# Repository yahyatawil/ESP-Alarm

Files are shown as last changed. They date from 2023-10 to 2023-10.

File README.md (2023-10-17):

# ESP-Alarm
This project was built for [Allaboutcircuit](https://www.allaboutcircuits.com/projects/esp-alarm-set-alarms-from-your-mobile-phone-esp8266-arduino-uno-wifi-iot/) published in 2017. 



## Hardware 
* Arduino UNO or any compatible board (optional).
* ATmega328P (optional).
* ESP8266 Wi-Fi module, ESP-01 model.
* 1.44-inch TFT display module.
* TP4056 breakout board (Li-ion battery charger).
* DS1307 (RTC chip)
* 74LVX4245 (5V-3V3 level converter)
* USB TTL converter cable (optional)





## Software / Arduino code
The code depends on the following libraries:

* TFT_ILI9163
* Adafruit_GFX
* DS1307RTC
* Wire (for I2C connection)
* EEPROM (to store alarms in the internal EEPROM)
* SoftwareSerial (optional debugging)

## Android App 

Many thanks to my friend Jihad Al-bathish (AKA Joud) for developing a native Android application for this project.

## Demo
https://www.youtube.com/watch?v=W3wOcIKqi2k

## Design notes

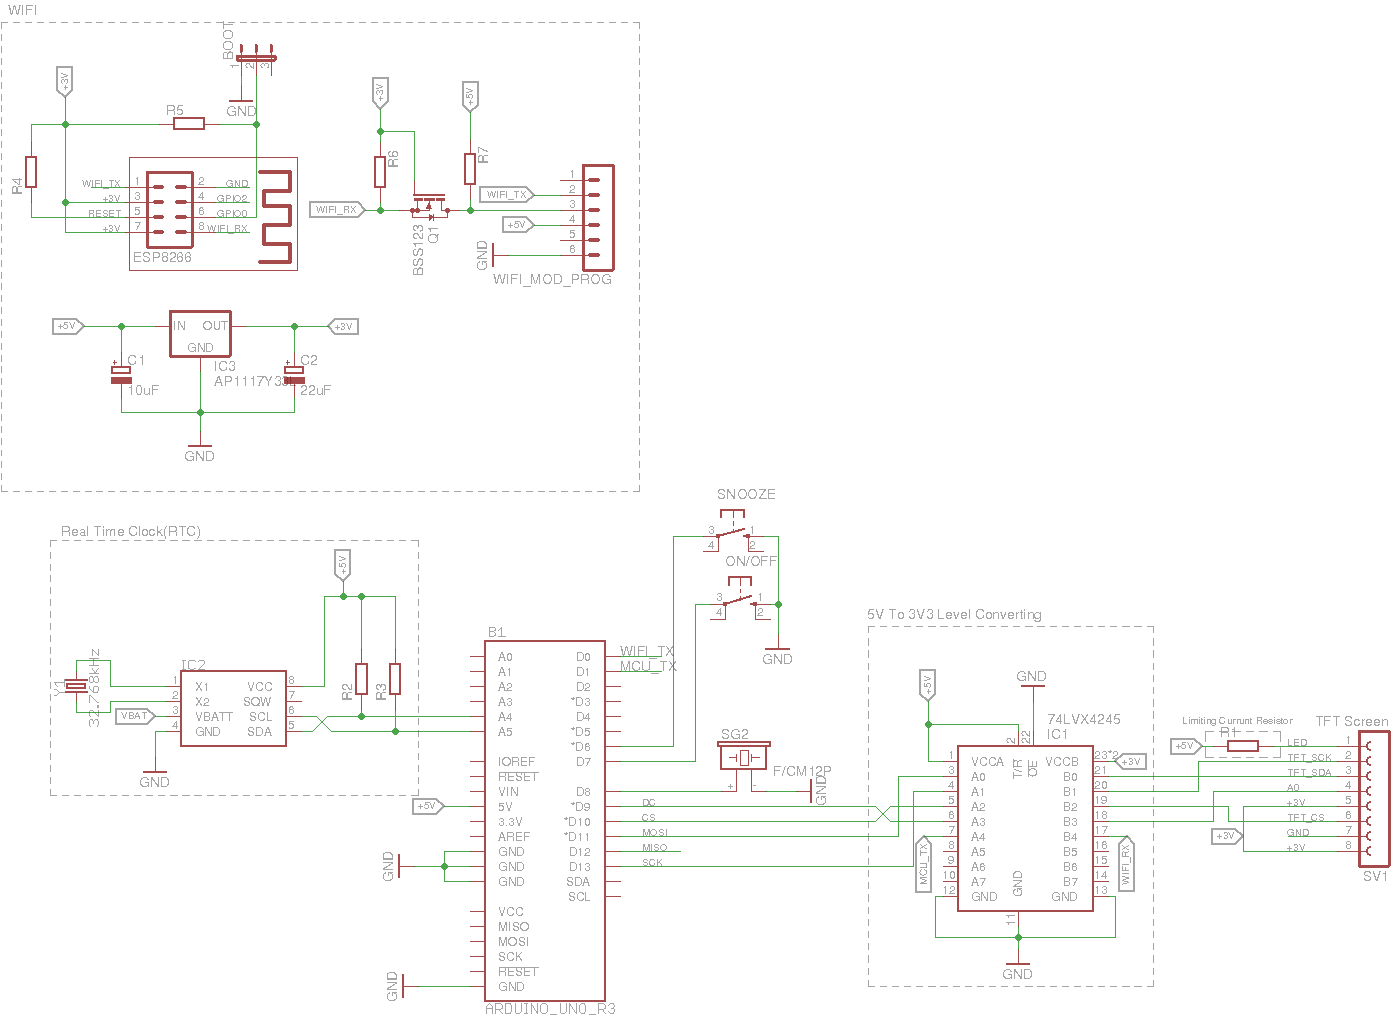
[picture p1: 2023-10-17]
PCB/sch.png

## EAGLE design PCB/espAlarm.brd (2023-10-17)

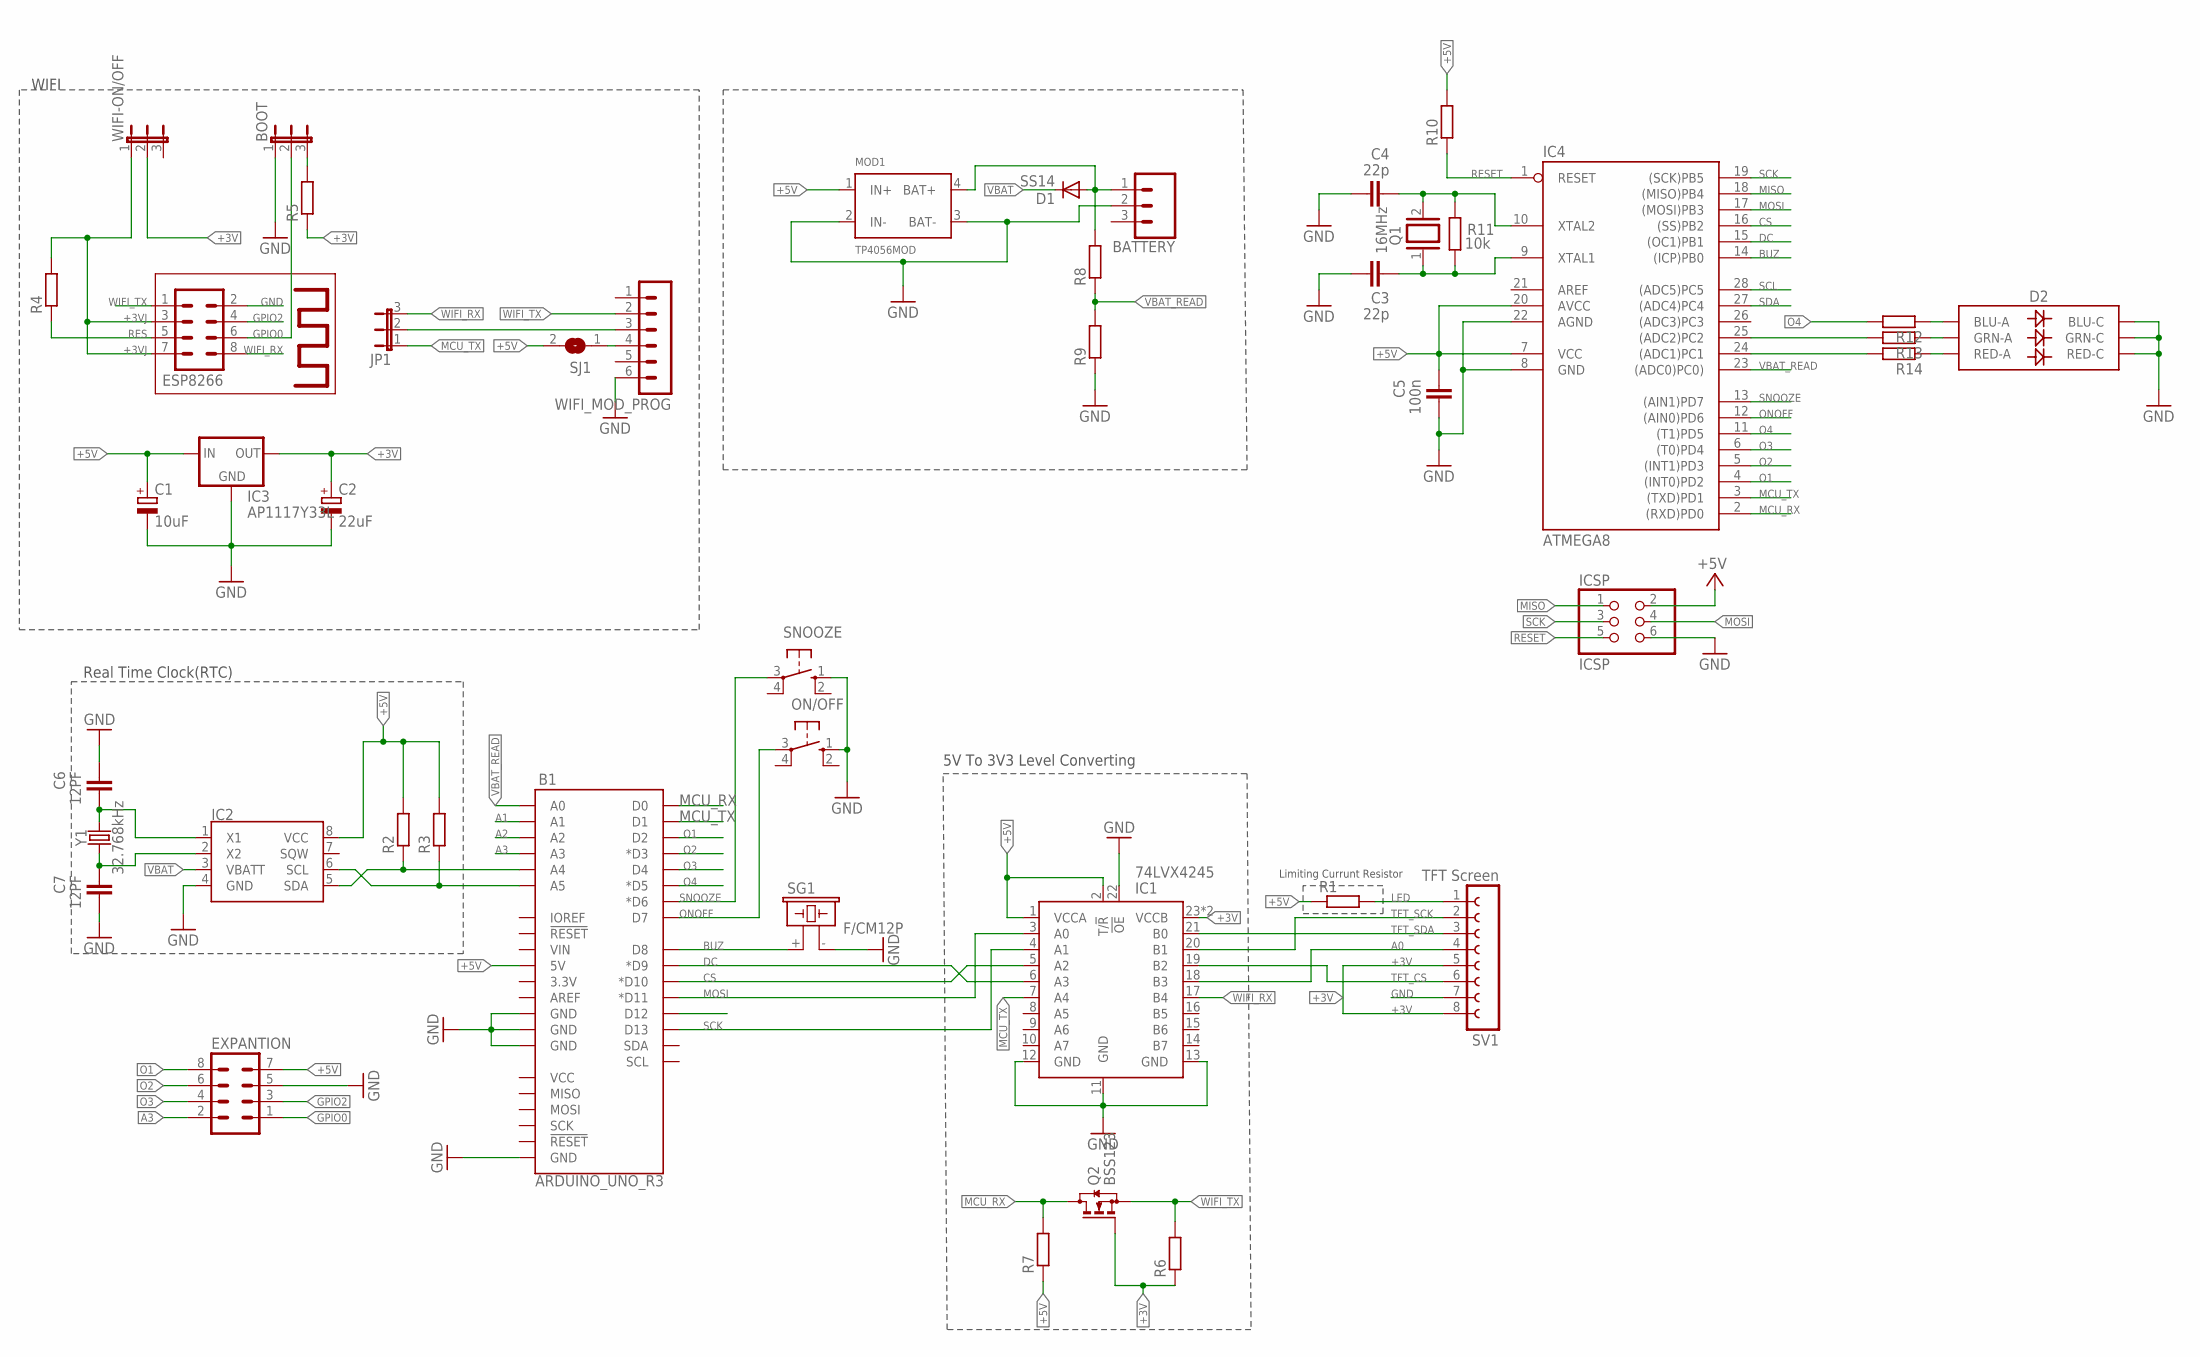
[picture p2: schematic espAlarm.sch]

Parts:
B1: ARDUINO_UNO_R3; ARDUINO_R3
BATTERY: CONN_03JST-PTH-VERT; JST-3-PTH-VERT
BOOT: JP2E; JP2
C1: 10uF; E2,5-7
C2: 22uF; E2,5-7
C3, C4: 22p; C0805
C5: 100n; C0805
C6, C7: 12PF; C0805
D1: SS14; DO214AC
D2: LED-RGBNO_IC; LED-TRICOLOR-5050
ESP8266: MA04-2
EXPANTION: MA04-2
IC1: 74LVX4245; TSSOP-24
IC2: DS1307; DIP-08
IC3: AP1117Y33L; SOT-89-3
IC4: ATMEGA8; DIL28-3
ICSP: ICSP; 2X03
JP1: JP2E; JP2
MOD1: TP4056MOD; TP4056BRD
ON/OFF: 10-XX; B3F-10XX
Q1: 16MHz; SMARTPRJ_QS
Q2: BSS123; SOT23
R1, R2, R3, R4, R5, R6, R7, R8, R9, R10, R12, R13, R14: R-EU_M1206; M1206
R11: 10k; M1206
SG1: F/CM12P
SJ1: SJ
SNOOZE: 10-XX; B3F-10XX
SV1: TFT Screen; FE08
WIFI-ON/OFF: JP2E; JP2
WIFI_MOD_PROG: MA06-1
Y1: 32.768kHz; CRYSTAL-PTH-2X6-CYL

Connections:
+3V: C2.+, IC1.23 (VCCB), IC1.24 (VCCB), IC3.3 (OUT), IC3.4 (OUT), Q2.1 (G), R5.1, R6.1, SV1.5, SV1.8, WIFI-ON/OFF.2
+3VJ: ESP8266.3, ESP8266.7, R4.2, WIFI-ON/OFF.1
+5V: B1.5V, C1.+, C5.2, EXPANTION.7, IC1.1 (VCCA), IC1.2 (T/!R), IC2.8 (VCC), IC3.1 (IN), IC4.7 (VCC), IC4.20 (AVCC), ICSP.2, MOD1.1 (IN+), R1.1, R2.2, R3.2, R7.1, R10.2, SJ1.2
A0: IC1.18 (B3), SV1.4
A1: B1.A1, IC4.24 ((ADC1)PC1), R14.2
A2: B1.A2, IC4.25 ((ADC2)PC2), R13.2
A3: B1.A3, EXPANTION.2
AREF: IC4.21 (AREF)
BUZ: B1.D8, IC4.14 ((ICP)PB0), SG1.+ (1)
CS: B1.D10 (*D10), IC1.5 (A2), IC4.16 ((SS)PB2)
DC: B1.D9 (*D9), IC1.6 (A3), IC4.15 ((OC1)PB1)
GND: B1.GND@1 (GND), B1.GND@2 (GND), B1.GND@3 (GND), B1.GND@4 (GND), BATTERY.2, BOOT.1, C1.-, C2.-, C3.1, C4.1, C5.1, C6.2, C7.1, D2.4 (BLU-C), D2.5 (RED-C), D2.6 (GRN-C), ESP8266.2, EXPANTION.5, IC1.11 (GND), IC1.12 (GND), IC1.13 (GND), IC1.22 (!OE), IC2.4 (GND), IC3.2 (GND), IC4.8 (GND), IC4.22 (AGND), ICSP.6, MOD1.2 (IN-), MOD1.3 (BAT-), ON/OFF.1 (S), R9.1, SG1.- (2), SNOOZE.1 (S), SV1.7, WIFI_MOD_PROG.6
GPIO0: BOOT.2, ESP8266.6, EXPANTION.1
GPIO2: ESP8266.4, EXPANTION.3
LED: R1.2, SV1.1
MCU_RX: B1.D0, IC4.2 ((RXD)PD0), Q2.3 (D), R7.2
MCU_TX: B1.D1, IC1.7 (A4), IC4.3 ((TXD)PD1), JP1.1
MISO: IC4.18 ((MISO)PB4), ICSP.1
MOSI: B1.D11 (*D11), IC1.3 (A0), IC4.17 ((MOSI)PB3), ICSP.4
unnamed: JP1.2, WIFI_MOD_PROG.3
unnamed: BOOT.3, R5.2
unnamed: C6.1, IC2.1 (X1), Y1.2
unnamed: C7.2, IC2.2 (X2), Y1.1
unnamed: SJ1.1, WIFI_MOD_PROG.4
unnamed: BATTERY.1, D1.A, MOD1.4 (BAT+), R8.2
unnamed: C3.2, IC4.9 (XTAL1), Q1.1, R11.1
unnamed: C4.2, IC4.10 (XTAL2), Q1.2, R11.2
unnamed: D2.3 (BLU-A), R12.1
unnamed: D2.1 (GRN-A), R13.1
unnamed: D2.2 (RED-A), R14.1
O1: B1.D2, EXPANTION.8, IC4.4 ((INT0)PD2)
O2: B1.D3 (*D3), EXPANTION.6, IC4.5 ((INT1)PD3)
O3: B1.D4, EXPANTION.4, IC4.6 ((T0)PD4)
O4: B1.D5 (*D5), IC4.11 ((T1)PD5), R12.2
ONOFF: B1.D7, IC4.12 ((AIN0)PD6), ON/OFF.3
RES: ESP8266.5, R4.1
RESET: IC4.1 (RESET), ICSP.5, R10.1
SCK: B1.D13, IC1.4 (A1), IC4.19 ((SCK)PB5), ICSP.3
SCL: B1.A5, IC2.6 (SCL), IC4.28 ((ADC5)PC5), R3.1
SDA: B1.A4, IC2.5 (SDA), IC4.27 ((ADC4)PC4), R2.1
SNOOZE: B1.D6 (*D6), IC4.13 ((AIN1)PD7), SNOOZE.3
TFT_CS: IC1.19 (B2), SV1.6
TFT_SCK: IC1.20 (B1), SV1.2
TFT_SDA: IC1.21 (B0), SV1.3
VBAT: D1.C, IC2.3 (VBATT)
VBAT_READ: B1.A0, IC4.23 ((ADC0)PC0)), R8.1, R9.2
WIFI_RX: ESP8266.8, IC1.17 (B4), JP1.3
WIFI_TX: ESP8266.1, Q2.2 (S), R6.2, WIFI_MOD_PROG.2

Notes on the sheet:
5V To 3V3 Level Converting
Limiting Currunt Resistor
Real Time Clock(RTC)
WIFI

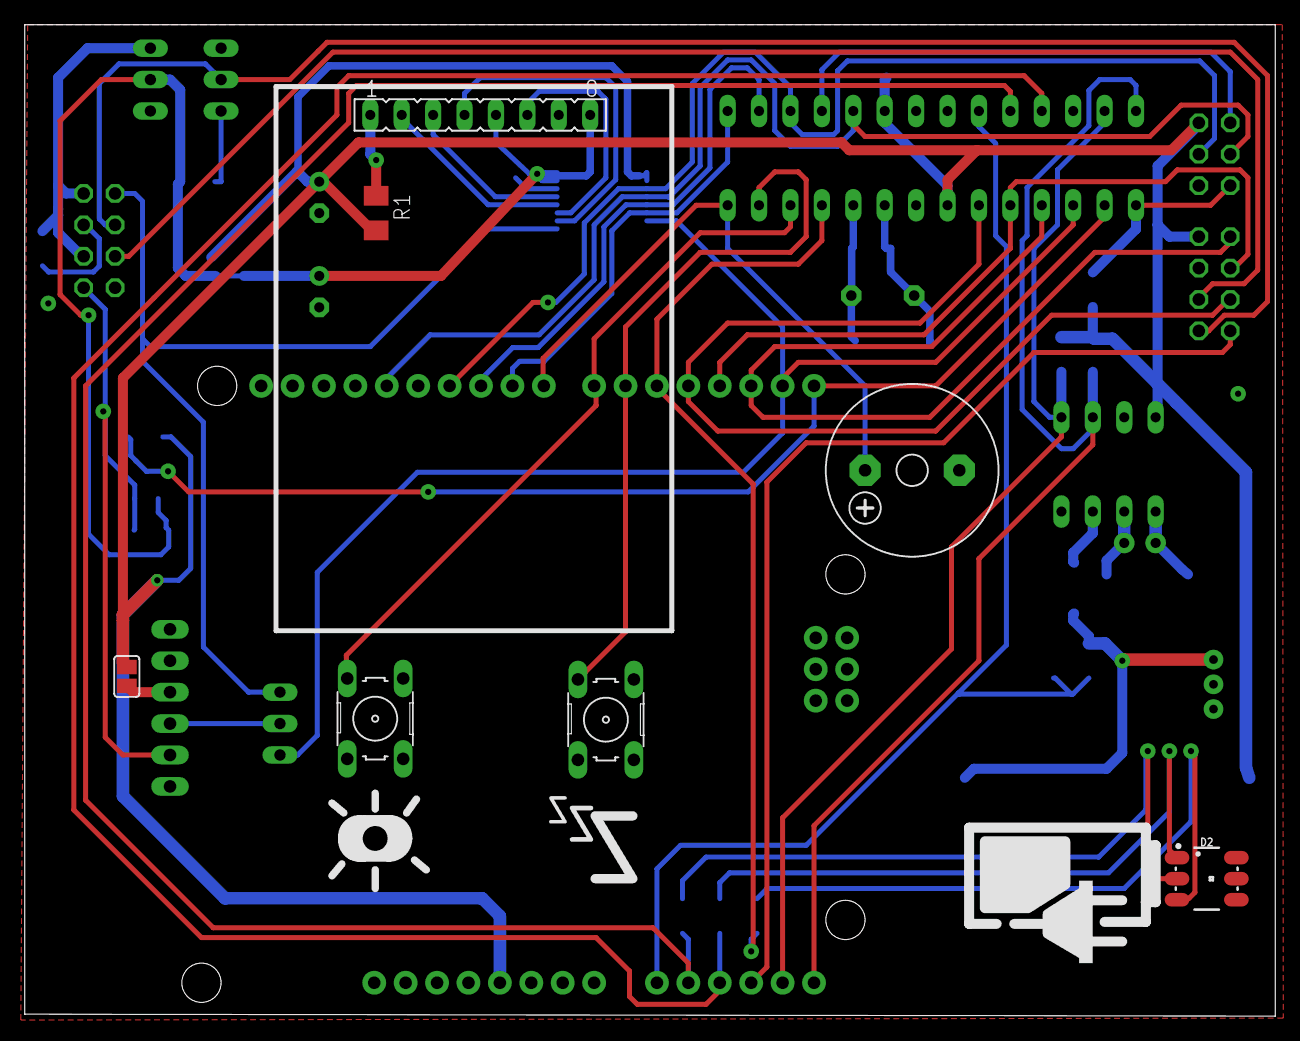
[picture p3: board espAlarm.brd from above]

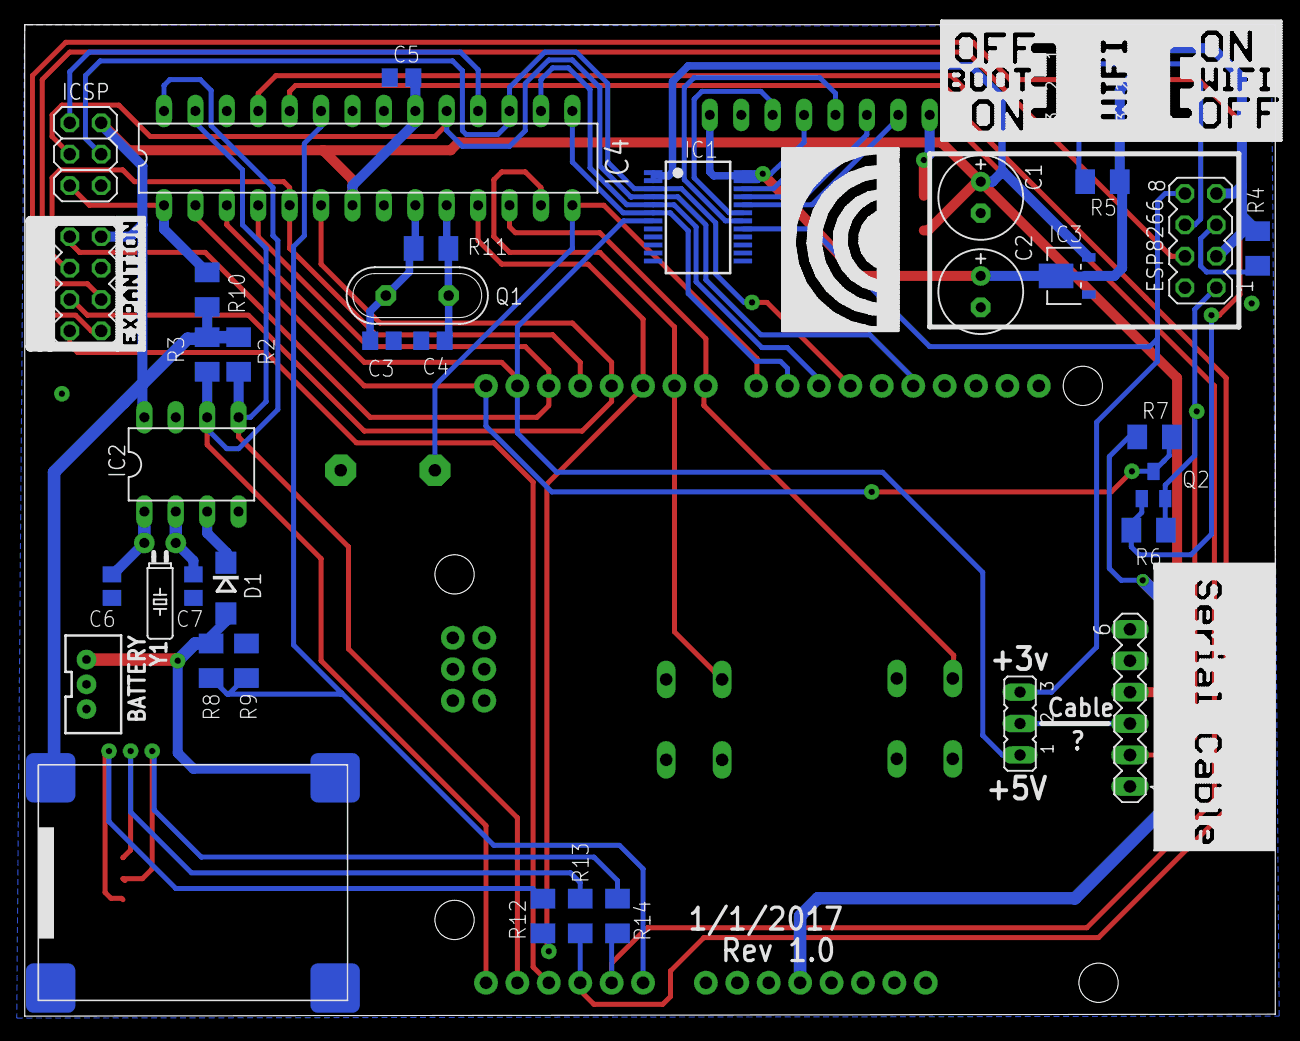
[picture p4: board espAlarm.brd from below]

Board: 2 copper layers, 101.1 x 80.2 mm, 45 parts (37 on the bottom side), 47 nets.

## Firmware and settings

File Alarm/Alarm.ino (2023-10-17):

/*
  Arduino With ESP8266 Controller

  This Sketch is for controlling some outputs of arduino by a direct command or
  by setting a timer for each output using a mobile application designed to communicate
  with arduino using ESP8266 module.

  This sketch is written for a tutorial published on http://allaboutcircuits.com/

  Please refer to the website to see the tutorial and to download mobile application

  Some parts of this Sketch is based on this tutorial code:
  http://allaboutee.com/2015/01/20/esp8266-android-application-for-arduino-pin-control/

  Created on June 2016
  Hardware and arduino code is by Yahya Tawil
  yahya.tawil_at_gmail.com
*/
//TODO app - DEBUG command - check alarm ID from app
//TODO add battery level on screen 
//TODO add power saving mode
//TODO Debug Level

//22 Byte for every alarm
//B0:ID
//B1:Active/Deactive
//B2:Hour
//B3:Minuit
//B4:Rep Day
//B5:sound 1..3
//B6..B21: Title 16 Byte

//Address = ID * 22

//Avalaible EEPROM size in Arduino UNO is 1024B

// 20 Alarm -> 20*22 = 440 B        000..439
// 16B Welcome Message              444..459
// 1B snooze time                   460

//1 Sun //2 Mon //3 Tue //4 Wed //5 Thu //6 Fri //7 Sat

#include <TFT_ILI9163C.h>
#include <SoftwareSerial.h>
#include <DS1307RTC.h>
#include <Wire.h>
#include <EEPROM.h>
#include <Adafruit_GFX.h>
#include <gfxfont.h>

#include "pitches.h"

#define DEBUG 1
//#define SWDebug // Disable(comment)/Enable(uncomment) software serial debugging using (PIN 2,3)
#define HTTPResponse // Disable(comment)/Enable(uncomment) Response from your device as HTTP response
//#define DebugOnTFT // Disable(comment)/Enable(uncomment) Printing debugging information on the TFT screen
#define ESPBaudRate 115200
#define HWSBaudRate 115200
#define SSBaudRate 9600

#define MaxRecordsNum 20
#define MaxRecordSize 22

#define Store_ID_ID 0
#define Store_ID_AD 1
#define Store_ID_HH 2
#define Store_ID_MM 3
#define Store_ID_Rep 4
#define Store_ID_Sound 5
#define Store_ID_Title 6

#define WelcomeMsgSize 16
#define WelcomeMsgAdd 444
#define SnoozeAdd     460

#define ReconnectPressVal 3
#define SnoozePin 6
#define OnOffPin 7
#define BuzzerPin 8

//uncomment Serial.*** if you want to use HW serial port (PIN 0,1) with ESP8266
//uncomment esp8266.*** if you want to use SW serial port (PIN 2,3) with ESP8266
//SoftwareSerial esp8266(2, 3); // make RX Arduino line is pin 2, make TX Arduino line is pin 3.
#define esp8266_Available() Serial.available() //esp8266.available()
#define esp8266_Find(ARG) Serial.find(ARG) //esp8266.find(ARG)
#define esp8266_Read() Serial.read() //esp8266.read()
#define esp8266_Write(ARG1,ARG2) Serial.write(ARG1,ARG2) //esp8266.write(ARG1,ARG2)
#define esp8266_Print(ARG) Serial.print(ARG) //esp8266.print(ARG)

#define TimePosOnScreen() tft.setCursor(10, 18)
#define DatePosOnScreen() tft.setCursor(2, 36)

#define TimeRecXYPos 0, 17
#define DateRecXYPos 0, 35
#define FreeSpaceXYPos 0, 52
#define FaddingXYPos 20, 70

#define TimeRecXYLen 128, 16
#define DateRecXYLen 128, 16

#ifdef SWDebug
SoftwareSerial SWSerial(2, 3); // make RX Arduino line is pin 2, make TX Arduino line is pin 3.
#endif
/*************/

tmElements_t tm;
String IP;

//const char *monthName[12]  = {"Jan", "Feb", "Mar", "Apr", "May", "Jun", "Jul", "Aug", "Sep", "Oct", "Nov", "Dec"};
//const char *DayName[7] = {"Sun", "Mon", "Tue", "Wed", "Thu", "Fri", "Sat"};

char RTC_Sec, RTC_Min, RTC_Hour, RTC_day, RTC_Mon, RTC_year, DayOfWeek;
char Sound_en, S_loop, snoozeTime, snoozeTimer, Sound_enTimer, activealarm, PressLong, SnoozePressLong;

unsigned long Active_Alarms_H [24];
unsigned long Active_Alarms_M [60];
unsigned long Active_Alarms_D [7];
unsigned char SnoozedAlarmsTimer[MaxRecordsNum];
char Rep_Alarms[MaxRecordsNum];
unsigned long SnoozedAlarms;

/*************/

/***Commands**/
#define Set "SET"
#define Add "ADD" // Request string from mobile application to know the state of each output
#define Del "DEL" // Request string from mobile application to make an output on
#define Sync "SYN" // Request string from mobile application to make an output off
#define Debug "DEB"
#define ResetMem "RES"

#define strResponseToSet "CT"
#define strResponseToAdd "AT"
#define strResponseToDel "DT"
#define strResponseToSyn "ST"
#define strResponseToRes "RT"
/*************/

// Color definitions
#define	BLACK   0x0000
#define	BLUE    0x001F
#define	RED     0xF800
#define	GREEN   0x07E0
#define CYAN    0x07FF
#define MAGENTA 0xF81F
#define YELLOW  0xFFE0
#define WHITE   0xFFFF
#define AACOrange 0xFC09

#define __CS 10
#define __DC 9

typedef struct _Alarm_t
{
  int ID;
  char AD;
  int Hour;
  int Minuit;
  int Rep;
  int sound;
  String Title;

} Alarm_t;

TFT_ILI9163C tft = TFT_ILI9163C(__CS, __DC);

void setup()
{
  tft.begin(); // Init for TFT screen

  Wire.begin(); // Init I2C for RTC chip

  Serial.begin(HWSBaudRate); // Serial port to send messages from arduino to computer

#ifdef SWDebug
  SWSerial.begin(SSBaudRate); // Software Serial port for printing debug messages
#endif

  PrintAACIntro(); //Print On the screen AAC Logo

  ConfigESP8266(); //Set Cconfiguration for ESP8266 like SSID, password, port number, ... etc

  ResetDateTime(); //Set default time for first run before sync with mobile time

  LoadArraies(); //load processing arries with values readed from EEPROM

  PrintInit(); // Print some informations on the screen

  digitalWrite(OnOffPin, true);
  digitalWrite(SnoozePin, true);

  pinMode(OnOffPin, INPUT_PULLUP);
  pinMode(SnoozePin, INPUT_PULLUP);
}


void loop()
{

#ifdef SWDebug
  if (SWSerial.read() == 'r')
  {
    for (int i = 0; i < 1024; i++)
      EEPROM.write(i, 0xFF);

    SWSerial.println("EEPROM Is Clear Now!");
  }
  if (SWSerial.read() == 'p')
    PrintStoredAlarms();
#endif

  if (PressLong > ReconnectPressVal)
  {
    PressLong = 0 ;
    setup(); //reconnect
  }

  if (Sound_en) // snoozeTime
  {

    if (S_loop)
    {
      tone(BuzzerPin, NOTE_C4);
    }
    else
      noTone(BuzzerPin);

    if (Sound_enTimer == 20 || PressLong > 0 || SnoozePressLong > 0)
    {
      Sound_en = 0;
      noTone(8);

      if (SnoozePressLong > 0)
      {
        SnoozePressLong = 0;
        SnoozedAlarms |= 1 << activealarm;
        SnoozedAlarmsTimer[activealarm];
      }
      else
      {
        PressLong = 0;
        unsigned char HH = LoadFromMem(activealarm, Store_ID_HH);
        unsigned char MM = LoadFromMem(activealarm, Store_ID_MM);

        if (Rep_Alarms[activealarm] != 'r')
        {
          Rep_Alarms[activealarm] = 'D' ;
          UpdateRec(activealarm, Store_ID_AD, 'D');
          Active_Alarms_H[HH] = Active_Alarms_H[HH] & (~(1 << activealarm));
          Active_Alarms_M[MM] = Active_Alarms_M[MM] & (~(1 << activealarm));
          Active_Alarms_D[DayOfWeek - 1] = Active_Alarms_D[DayOfWeek - 1] & (~(1 << activealarm));
        }
      }
      tft.fillRect(FreeSpaceXYPos, 128, 128, BLACK);
      FaddingText("OFF", FaddingXYPos);

    }
  }
  else
  {
    noTone(BuzzerPin);
  }

  RTC.read(tm);

  if (RTC_Hour != tm.Hour || RTC_Min != tm.Minute  || RTC_Sec != tm.Second )
  {
    Sound_enTimer++;
    S_loop ^= 1;

    if (digitalRead(OnOffPin) == false)
      PressLong++;

    if (digitalRead(SnoozePin) == false)
      SnoozePressLong++;

    unsigned long activeAlarms;
    if (RTC_Min != tm.Minute )
    {
      snoozeTimer++;
      activeAlarms = Active_Alarms_H[tm.Hour] & Active_Alarms_M[tm.Minute] & Active_Alarms_D[DayOfWeek - 1];
      for (int i = 0; i < MaxRecordsNum; i++)
      {
        if (SnoozedAlarms & (1 << i) && (SnoozedAlarmsTimer[i] < snoozeTime))
          SnoozedAlarmsTimer[i]++;
      }
      for (int i = 0; i < MaxRecordsNum; i++)
      {
        if ((activeAlarms & (1 << i)) &&  ((Rep_Alarms[i] == 'r') || ((Rep_Alarms[i] == 'O'))))
        {
          Sound_en = 1;
          Sound_enTimer = 0;
          activealarm = i;
#ifdef DebugOnTFT
          FaddingText("ON", FaddingXYPos);
#endif
          PrintAlarmTitle(i);
          break;
        }
      }
      for (int i = 0; i < MaxRecordsNum; i++)
      {
        if ((SnoozedAlarms & (1 << i)) && (SnoozedAlarmsTimer[i] == snoozeTime))
        {
          Sound_en = 1;
          Sound_enTimer = 0;
          SnoozePressLong = 0;
          activealarm = i;
          if (SnoozedAlarms & (1 << activealarm))
            SnoozedAlarms &= (~( 1 << activealarm));
#ifdef DebugOnTFT
          tft.setCursor(FreeSpaceXYPos);
          tft.setTextColor(WHITE);
          tft.setTextSize(1);
          tft.print(SnoozedAlarms);
          delay(2000);
          tft.fillRect(FreeSpaceXYPos, 128, 128, BLACK);

          String FaddingT = "Snoozed";
          FaddingT += activealarm;
          FaddingText(FaddingT, FaddingXYPos);
#endif
          PrintAlarmTitle(i);
          break;
        }
      }
    }

    RTC_Hour = tm.Hour;
    RTC_Min = tm.Minute;
    RTC_Sec = tm.Second;

    PrintTimeOnScreen(tm);
  }
  if (RTC_day != tm.Day || RTC_Mon != tm.Month || RTC_year != tm.Year)
  {
    if (RTC_day != tm.Day)
    {
      while (Sound_en); //don't change the day before finishing the current alarm
      if (DayOfWeek == 7)
        DayOfWeek = 1;
      else
        DayOfWeek++;
    }

    RTC_day = tm.Day;
    RTC_Mon = tm.Month;
    RTC_year = tm.Year;

    PrintDateOnScreen(tm);//todo refresh day of the week
  }
  if (esp8266_Available()) // check if the esp is sending a message
  {
    if (esp8266_Find("+IPD,"))
    {
      delay(1000); // wait for the serial buffer to fill up (read all the serial data)

      int connectionId = esp8266_Read() - 48; // get the connection id so that we can then disconnect
      // subtract 48 because the read() function returns the ASCII decimal value and 0 (the first decimal number) starts at 48

      String closeCommand = "AT+CIPCLOSE=";//Setting up the close connecting command
      closeCommand += connectionId; // append connection id
      closeCommand += "\r\n";

      esp8266_Find('?'); // This caracter define the start of command in the our message body

      String InStream;
      InStream = (char) esp8266_Read();
      InStream += (char) esp8266_Read();
      InStream += (char) esp8266_Read();
      //      for (int i = 0; i < 25; i++)
      //        InStream += (char) esp8266_Read();
      //      tft.setCursor(FaddingXYPos);
      //      tft.setTextColor(WHITE);
      //      tft.setTextSize(1);
      //      tft.print(InStream);
      //      return;

#ifdef SWDebug
      if (DEBUG)
        SWSerial.println(InStream);
#endif
      if (InStream.equals(Sync)) //Example: SYN,08+20+2016,09:28:56,1
      {
        esp8266_Read();//Read ','

        char DBuf[10]; // 08+20+2016
        char TBuf[8];  // 09:28:56
        for (int i = 0; i < 10; i++)
          DBuf[i] = esp8266_Read();
        getDate(DBuf);

        esp8266_Read();//Read ','

        for (int i = 0; i < 8; i++)
          TBuf[i] = esp8266_Read();
        getTime(TBuf);

        RTC.write(tm);

        esp8266_Read();//Read ','

        DayOfWeek = esp8266_Read() - 48;

        RTC_day = tm.Day;
        RTC_Mon = tm.Month;
        RTC_year = tm.Year;
        RTC_Hour = tm.Hour;
        RTC_Min = tm.Minute;
        RTC_Sec = tm.Second;

        PrintDateOnScreen(tm);
        PrintTimeOnScreen(tm);

#ifdef HTTPResponse
        sendHTTPResponse(connectionId, strResponseToSyn);
#else
        sendResponse(connectionId, ResponseToSyn);
#endif
        sendCommand(closeCommand, 1000, DEBUG); // close connection

        FaddingText("Sync", FaddingXYPos);
      }

      else if (InStream.equals(Add) || InStream.equals(Del)) // ADD,ID,A(active)/D(deactive),HHMM,RepDays,SoundType,Title
      {
        Alarm_t Alarm_temp;

        esp8266_Read();//Read ','

        int Alarm_ID = (esp8266_Read() - 48);
        int Alarm_ID_dig2 = esp8266_Read();
        if (Alarm_ID_dig2 == ',')
          Alarm_temp.ID = Alarm_ID;
        else
        {
          Alarm_ID *= 10;
          Alarm_ID += (Alarm_ID_dig2 - 48);
          Alarm_temp.ID = Alarm_ID - 1;
          esp8266_Read();//Read ','
        }

        if (Alarm_ID > MaxRecordsNum)
        {
#ifdef HTTPResponse
          sendHTTPResponse(connectionId, "ERR");
#else
          sendResponse(connectionId, "ERR");
#endif
          sendCommand(closeCommand, 1000, DEBUG); // close connection
        }

        char Alarm_AD;

        Alarm_AD = esp8266_Read();

        Alarm_temp.AD = Alarm_AD ;

        if (Alarm_AD == 'A')
        {
          esp8266_Read();//Read ','
          int Alarm_HH = (esp8266_Read() - 48);
          int Alarm_HH_dig2 = (esp8266_Read() - 48);
          if (Alarm_HH_dig2 >= 0 && Alarm_HH_dig2 <= 9)
          {
            Alarm_HH *= 10;
            Alarm_HH += Alarm_HH_dig2;
          }

          Alarm_temp.Hour = Alarm_HH ;

          int Alarm_MM = (esp8266_Read() - 48);
          int Alarm_MM_dig2 = (esp8266_Read() - 48);
          if (Alarm_MM_dig2 >= 0 && Alarm_MM_dig2 <= 9)
          {
            Alarm_MM *= 10;
            Alarm_MM += Alarm_MM_dig2;
          }

          Alarm_temp.Minuit = Alarm_MM;
          esp8266_Read();//Read ','

          char Alarm_Rep = esp8266_Read() - 48;
          bool Rep_day[7] = {0, 0, 0, 0, 0, 0, 0}; // Sun Mon Tue Wed Thu Fri Sat
          int HEX_val;
          if ((Alarm_Rep + 48) == 'O' || (Alarm_Rep + 48) == 'F') // O - no repeat , F - all days , ex: 123 means repeat alarm on Mon+Tue+Wed
          {
            HEX_val = Alarm_Rep + 48;
            esp8266_Read();//Read ','
          }
          else
          {
            for (int i = 0; i < 6; i++)
            {
              if ((Alarm_Rep + 48) == ',') //end of rep segment
                break;
              else
              {
                Rep_day[Alarm_Rep - 1] = 1; // ex: Rep_day[1-1(Sun)]=1
                Alarm_Rep = esp8266_Read() - 48;
              }
            }
            HEX_val = 0;
            for (int i = 0; i < 7; i++) // convert to hex value
            {
              if (Rep_day[i])
              {
                HEX_val |= (1 << i);
              }
            }
          }
          Alarm_temp.Rep = HEX_val;

          int Alarm_ST = (esp8266_Read() - 48);
          Alarm_temp.sound = Alarm_ST;

          esp8266_Read();//Read ','

          char InStream;
          String Alarm_title;

          for (int i = 0; i < 16; i++)
          {
            InStream = esp8266_Read();
            Alarm_title += InStream;
            if (InStream == ';')
              break;
          }
          Alarm_temp.Title = Alarm_title;

          UpdateArraies(Alarm_temp);
          StoreAlarmToEEPROM(Alarm_temp);
        }
        else if (Alarm_AD == 'D' )
        {
          UpdateRec(Alarm_ID, Store_ID_AD, 'D');
          Rep_Alarms[Alarm_ID] = 'D';
        }
String Response;
          if(InStream.equals(Del))
          {
#ifdef HTTPResponse
          sendHTTPResponse(connectionId, strResponseToDel);
#else
          sendResponse(connectionId, strResponseToDel);
#endif
        sendCommand(closeCommand, 1000 , DEBUG); // close connection
          FaddingText("Deleted", FaddingXYPos);
          }

          else if(InStream.equals(Add))
          {
        Response = strResponseToAdd;
        Response +=  Alarm_ID;
#ifdef HTTPResponse
        sendHTTPResponse(connectionId, Response);
#else
        sendResponse(connectionId, Response);
#endif
        sendCommand(closeCommand, 1000 , DEBUG); // close connection

        FaddingText("Added!", FaddingXYPos);
          }

#ifdef DebugOnTFT
        tft.setTextSize(1);
        tft.setTextColor(WHITE);
        tft.setCursor(FreeSpaceXYPos);
        for (int j = 0; j <  7; j++)
        {
          tft.print("D>");
          tft.print(Active_Alarms_D[j]);
        }
        tft.print(",M>");
        tft.print(Active_Alarms_M[Alarm_temp.Minuit]);
        tft.print(",H>");
        tft.print(Active_Alarms_H[Alarm_temp.Hour]);
        tft.print(",>R");
        tft.print(Rep_Alarms[Alarm_ID]);
        delay(10000);
        tft.fillRect(FreeSpaceXYPos, 128, 128, BLACK);

        tft.setCursor(FreeSpaceXYPos);
        for (int j = 0; j <  MaxRecordSize; j++)
        {
          tft.print(EEPROM.read(Alarm_ID * MaxRecordSize + j));
          tft.print(',');
        }
        delay(10000);
        tft.fillRect(FreeSpaceXYPos, 128, 128, BLACK);
#endif

      }

      else if (InStream.equals(Set)) // ex: SET,5,Hello; --- 5Min snooze time and "Hello" is the welcome meassage
      {
        char temp, temp_dig2, SnoozeTime;
        char msg[16];
        esp8266_Read();//Read ','
        temp = esp8266_Read() - 48;
        temp_dig2 = esp8266_Read();
        if (temp_dig2 == ',')
          SnoozeTime = temp;
        else
          SnoozeTime = temp * 10 + (temp_dig2 - 48);
        for (int i = 0; i < 16; i++)
        {
          temp = esp8266_Read();
          msg[i] = temp;
          if (temp == ';')
            break;
        }

#ifdef HTTPResponse
        sendHTTPResponse(connectionId, strResponseToSet);
#else
        sendResponse(connectionId, ResponseToSet);
#endif
        sendCommand(closeCommand, 1000 , DEBUG); // close connection

        UpdateSetting(msg, SnoozeTime);
        FaddingText("Set!", FaddingXYPos);
      }
#ifdef DebugOnTFT
      else if (InStream.equals(Debug)) //Printing bebugging informations on the screen
      {
        //  SWSerial.println("\tID\tAD\tHour\tMin\tRep\tsound");

        tft.setTextSize(1);
        tft.setTextColor(WHITE);
        tft.setCursor(FreeSpaceXYPos);
        for (int i = 0; i < MaxRecordsNum; i++) // 20 Alarm
        {
          tft.setTextColor(RED);
          tft.print(i);
          tft.print("#");
          tft.setTextColor(WHITE);
          for (int j = 0; j <  MaxRecordSize; j++)
          {
            tft.print(EEPROM.read(i * MaxRecordSize + j));
            tft.print('|');
          }
          if (tft.getCursorY() > 90 || i == (MaxRecordsNum - 1))
          {
            delay(5000);
            tft.fillRect(FreeSpaceXYPos, 128, 128, BLACK);
            tft.setCursor(FreeSpaceXYPos);
          }

        }

        for (int j = 0; j <  60; j++)
        {
          tft.setTextColor(RED);
          tft.print(j);
          tft.print("M>");
          tft.setTextColor(WHITE);
          tft.println(Active_Alarms_M[j]);
          if (tft.getCursorY() > 120 || j == 59)
          {
            delay(3000);
            tft.fillRect(FreeSpaceXYPos, 128, 128, BLACK);
            tft.setCursor(FreeSpaceXYPos);
          }
        }

        for (int j = 0; j <  24; j++)
        {
          tft.setTextColor(RED);
          tft.print(j);
          tft.print("H>");
          tft.setTextColor(WHITE);
          tft.println(Active_Alarms_H[j]);
          if (tft.getCursorY() > 120 || j == 23)
          {
            delay(3000);
            tft.fillRect(FreeSpaceXYPos, 128, 128, BLACK);
            tft.setCursor(FreeSpaceXYPos);
          }
        }

        for (int j = 0; j <  7; j++)
        {
          tft.setTextColor(RED);
          tft.print(j);
          tft.print("D>");
          tft.setTextColor(WHITE);
          tft.println(Active_Alarms_D[j]);
          if (tft.getCursorY() > 120 || j == 6 )
          {
            delay(3000);
            tft.fillRect(FreeSpaceXYPos, 128, 128, BLACK);
            tft.setCursor(FreeSpaceXYPos);
          }
        }

        for (int j = 0; j <  MaxRecordsNum; j++)
        {
          tft.setTextColor(RED);
          tft.print(j);
          tft.print(">R");
          tft.setTextColor(WHITE);
          tft.println(Rep_Alarms[j]);
          if (tft.getCursorY() > 120 || j == (MaxRecordsNum - 1))
          {
            delay(3000);
            tft.fillRect(FreeSpaceXYPos, 128, 128, BLACK);
            tft.setCursor(FreeSpaceXYPos);
          }
        }

      }
#endif
      else if (InStream.equals(ResetMem))
      {
        sendCommand(closeCommand, 1000 , DEBUG); // close connection
        for (int i = 0; i < 1024; i++)
          EEPROM.write(i, 0xFF);

#ifdef HTTPResponse
        sendHTTPResponse(connectionId, strResponseToRes);
#else
        sendResponse(connectionId, ResponseToRes);
#endif

        FaddingText("RESET", FaddingXYPos);
        setup();
      }

      else // unsupported command is recived
      {
#ifdef HTTPResponse
        sendHTTPResponse(connectionId, "ERR");
#else
        sendResponse(connectionId, "ERR");
#endif
        sendCommand(closeCommand, 1000, DEBUG); // close connection
      }
    }
  }
}

/**********************************Start********************************/
/****************************Memory Functions***************************/
/***********************************************************************/

void UpdateSetting(char * msg, char snooze)
{
  for (int i = 0; i < WelcomeMsgSize; i++)
  {
    EEPROM.write(WelcomeMsgAdd + i, *(msg + i));
    if (*(msg + i) == ';')
      break;
  }
  EEPROM.write(SnoozeAdd, snooze);
  snoozeTime = snooze;
}


unsigned char LoadFromMem(int id, int Store_id)
{
  unsigned int add = id * MaxRecordSize + Store_id   ;
  return EEPROM.read(add);
}

void StoreAlarmToEEPROM(Alarm_t alarm)
{
  //store number in EEPROM
  unsigned int add = alarm.ID * MaxRecordSize;

#ifdef SWDebug
  SWSerial.println("Alarm:");
  SWSerial.println(alarm.ID);
  SWSerial.println(alarm.AD);
  SWSerial.println(alarm.Hour);
  SWSerial.println(alarm.Minuit);
  SWSerial.println(alarm.Rep);
  SWSerial.println(alarm.sound);
#endif
  EEPROM.update(add++, (char)alarm.ID);
  EEPROM.update(add++, (char)alarm.AD);
  EEPROM.update(add++, (char)alarm.Hour);
  EEPROM.update(add++, (char)alarm.Minuit);
  EEPROM.update(add++, (char)alarm.Rep);
  EEPROM.update(add++, (char)alarm.sound);

  for (int i = 0; i < alarm.Title.length(); i++)
    EEPROM.update(add++, alarm.Title[i]);

}

void UpdateRec(int id, int Store_id, int val)
{
  unsigned int add = id  * MaxRecordSize + Store_id;
  EEPROM.write(add, val);
}
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

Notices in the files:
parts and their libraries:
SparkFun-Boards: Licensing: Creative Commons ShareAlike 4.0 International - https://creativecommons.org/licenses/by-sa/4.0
